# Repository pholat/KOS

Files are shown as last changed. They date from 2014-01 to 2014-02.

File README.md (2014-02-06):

KOS
===

Another RepRap controller based on teensylu/printrboard and more. Controller is designed in last developer version of KiCAD EDA, moreover it is compatibile with teensylu 0.8. If you use Marlin, all you need is to choose teensylu board.

Teensylu-lvlup-0.9v125 is licenced under Creative Commons Attribution-ShareAlike 4.0 International 
http://creativecommons.org/licenses/by-sa/4.0/legalcode

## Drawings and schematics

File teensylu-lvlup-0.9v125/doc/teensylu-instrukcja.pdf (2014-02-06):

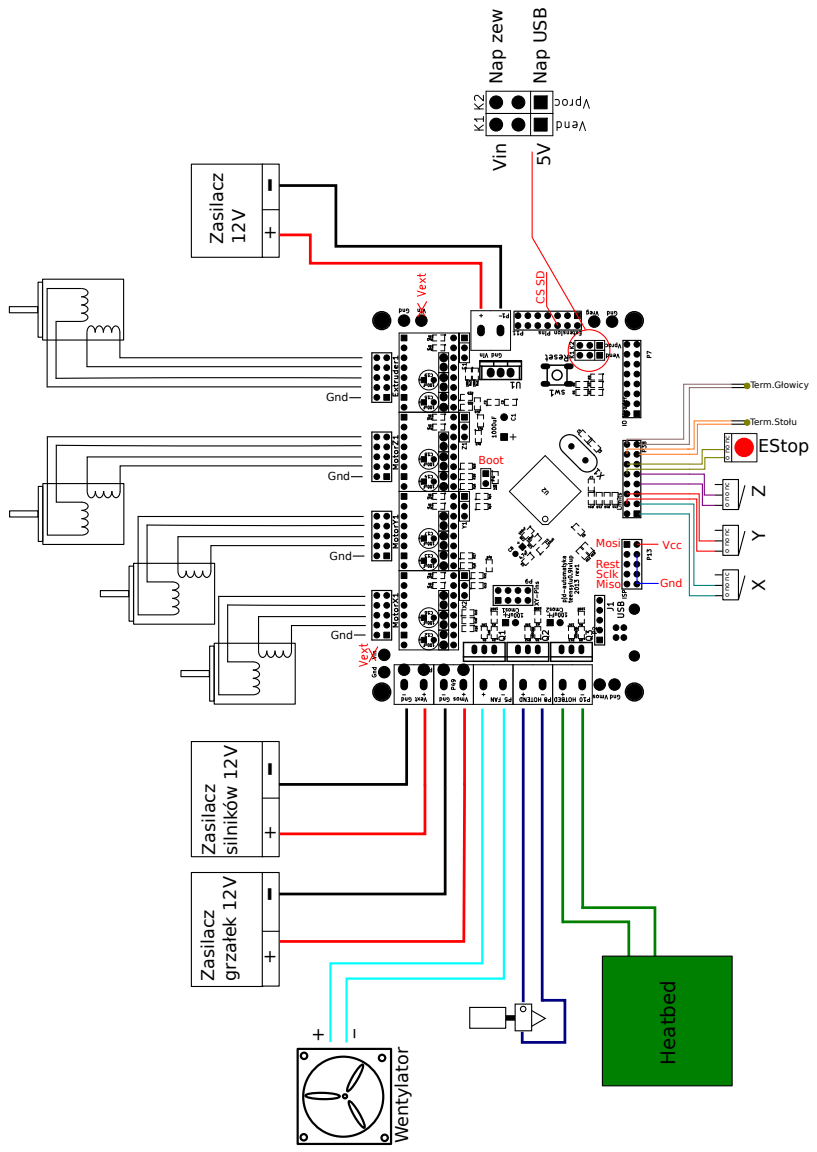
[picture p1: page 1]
Zasilacz; grzałek 12V; silników 12V + - + -; Heatbed; Term.Stołu; Term.Głowicy; Nap zew; Nap USB; Vin; Gnd; Mosi; Vcc; Rest Sclk Miso; Boot; EStop; Wentylator

## 1 Krańcówki

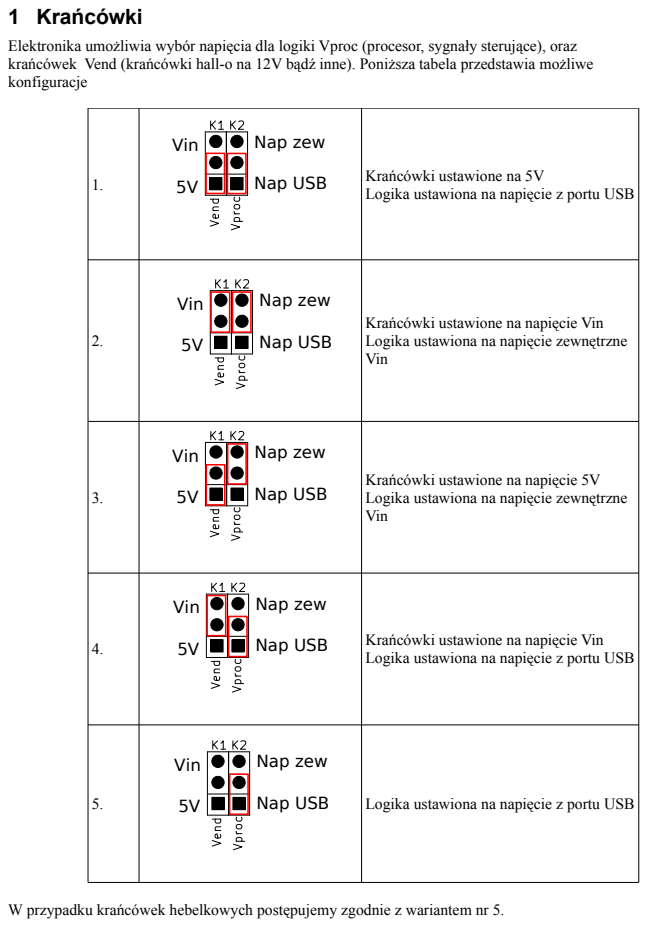
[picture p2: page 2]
Nap zew; Nap USB; Vin

Elektronika umożliwia wybór napięcia dla logiki Vproc (procesor, sygnały sterujące), oraz
krańcówek Vend (krańcówki hall-o na 12V bądź inne). Poniższa tabela przedstawia możliwe
konfiguracje

1. Krańcówki ustawione na 5V | Logika ustawiona na napięcie z portu USB

2. | Krańcówki ustawione na napięcie Vin Logika ustawiona na napięcie zewnętrzne Vin

3. | Krańcówki ustawione na napięcie 5V Logika ustawiona na napięcie zewnętrzne Vin

4. Krańcówki ustawione na napięcie Vin | Logika ustawiona na napięcie z portu USB

5. Logika ustawiona na napięcie z portu USB

W przypadku krańcówek hebelkowych postępujemy zgodnie z wariantem nr 5.

## 2 Stepstick

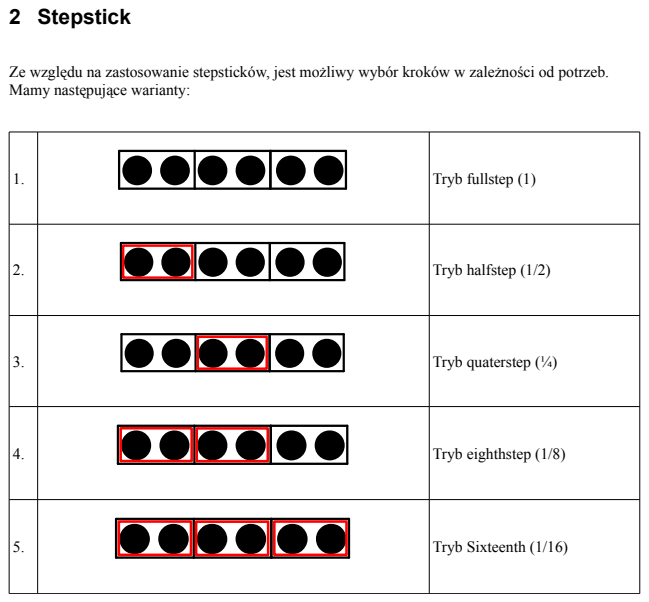
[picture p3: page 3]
1. Tryb fullstep (1); 2. Tryb halfstep (1/2); 3. Tryb quaterstep (¼); 4. Tryb eighthstep (1/8); 5. Tryb Sixteenth (1/16)

Ze względu na zastosowanie stepsticków, jest możliwy wybór kroków w zależności od potrzeb.
Mamy następujące warianty:

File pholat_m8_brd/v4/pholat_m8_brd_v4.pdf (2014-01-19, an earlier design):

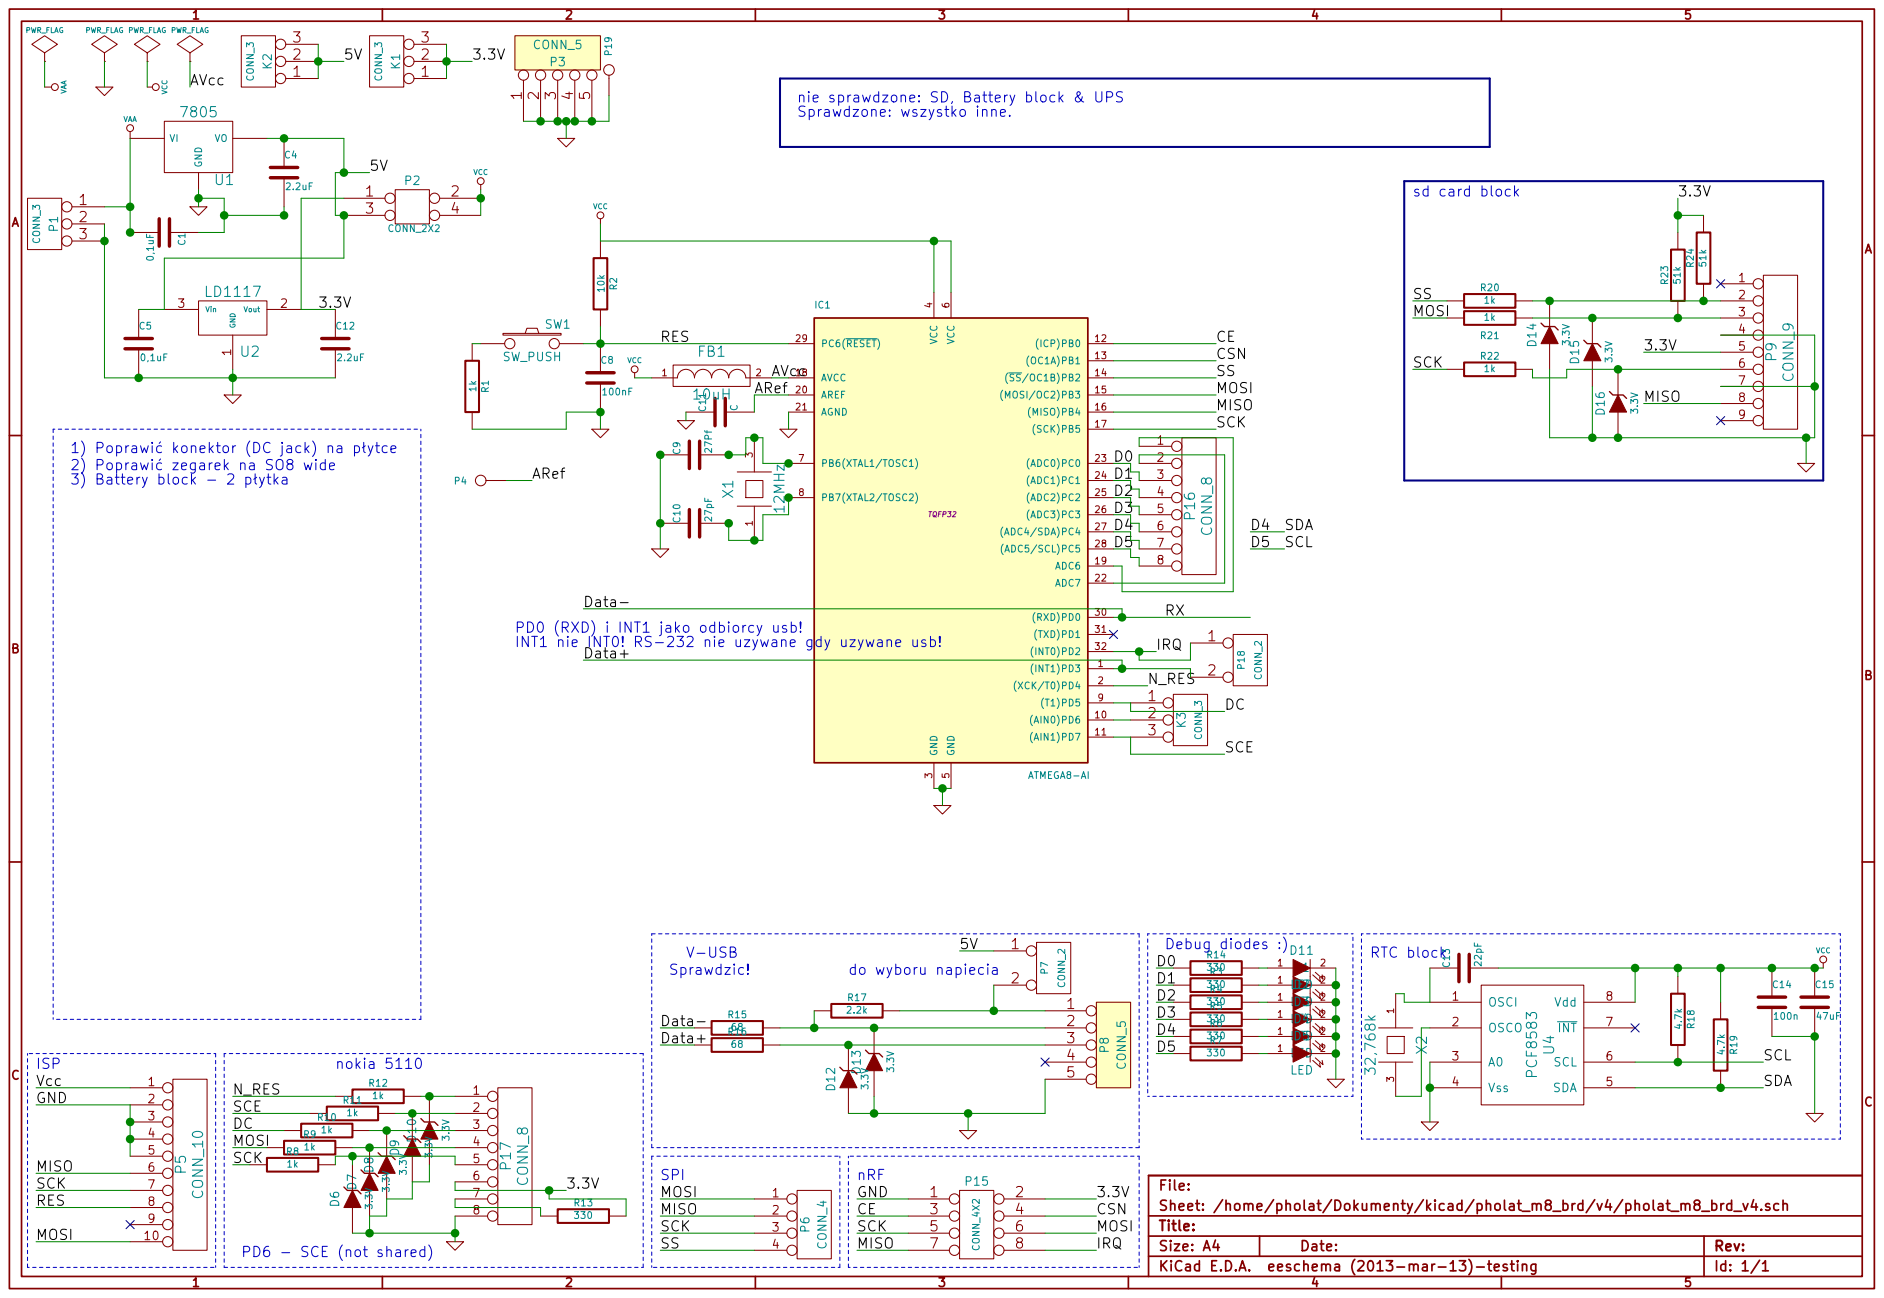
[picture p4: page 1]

nie sprawdzone: SD, Battery block & UPS
Sprawdzone: wszystko inne.

VCC 1) Poprawi konektor (DC jack) na pytce
2) Poprawi zegarek na SO8 wide
3) Battery block - 2 pytka

PD0 (RXD) i INT1 jako odbiorcy usb!
INT1 nie INT0! RS-232 nie uzywane gdy uzywane usb!

C Sheet: /home/pholat/Dokumenty/kicad/pholat_m8_brd/v4/pholat_m8_brd_v4.sch File: Title:

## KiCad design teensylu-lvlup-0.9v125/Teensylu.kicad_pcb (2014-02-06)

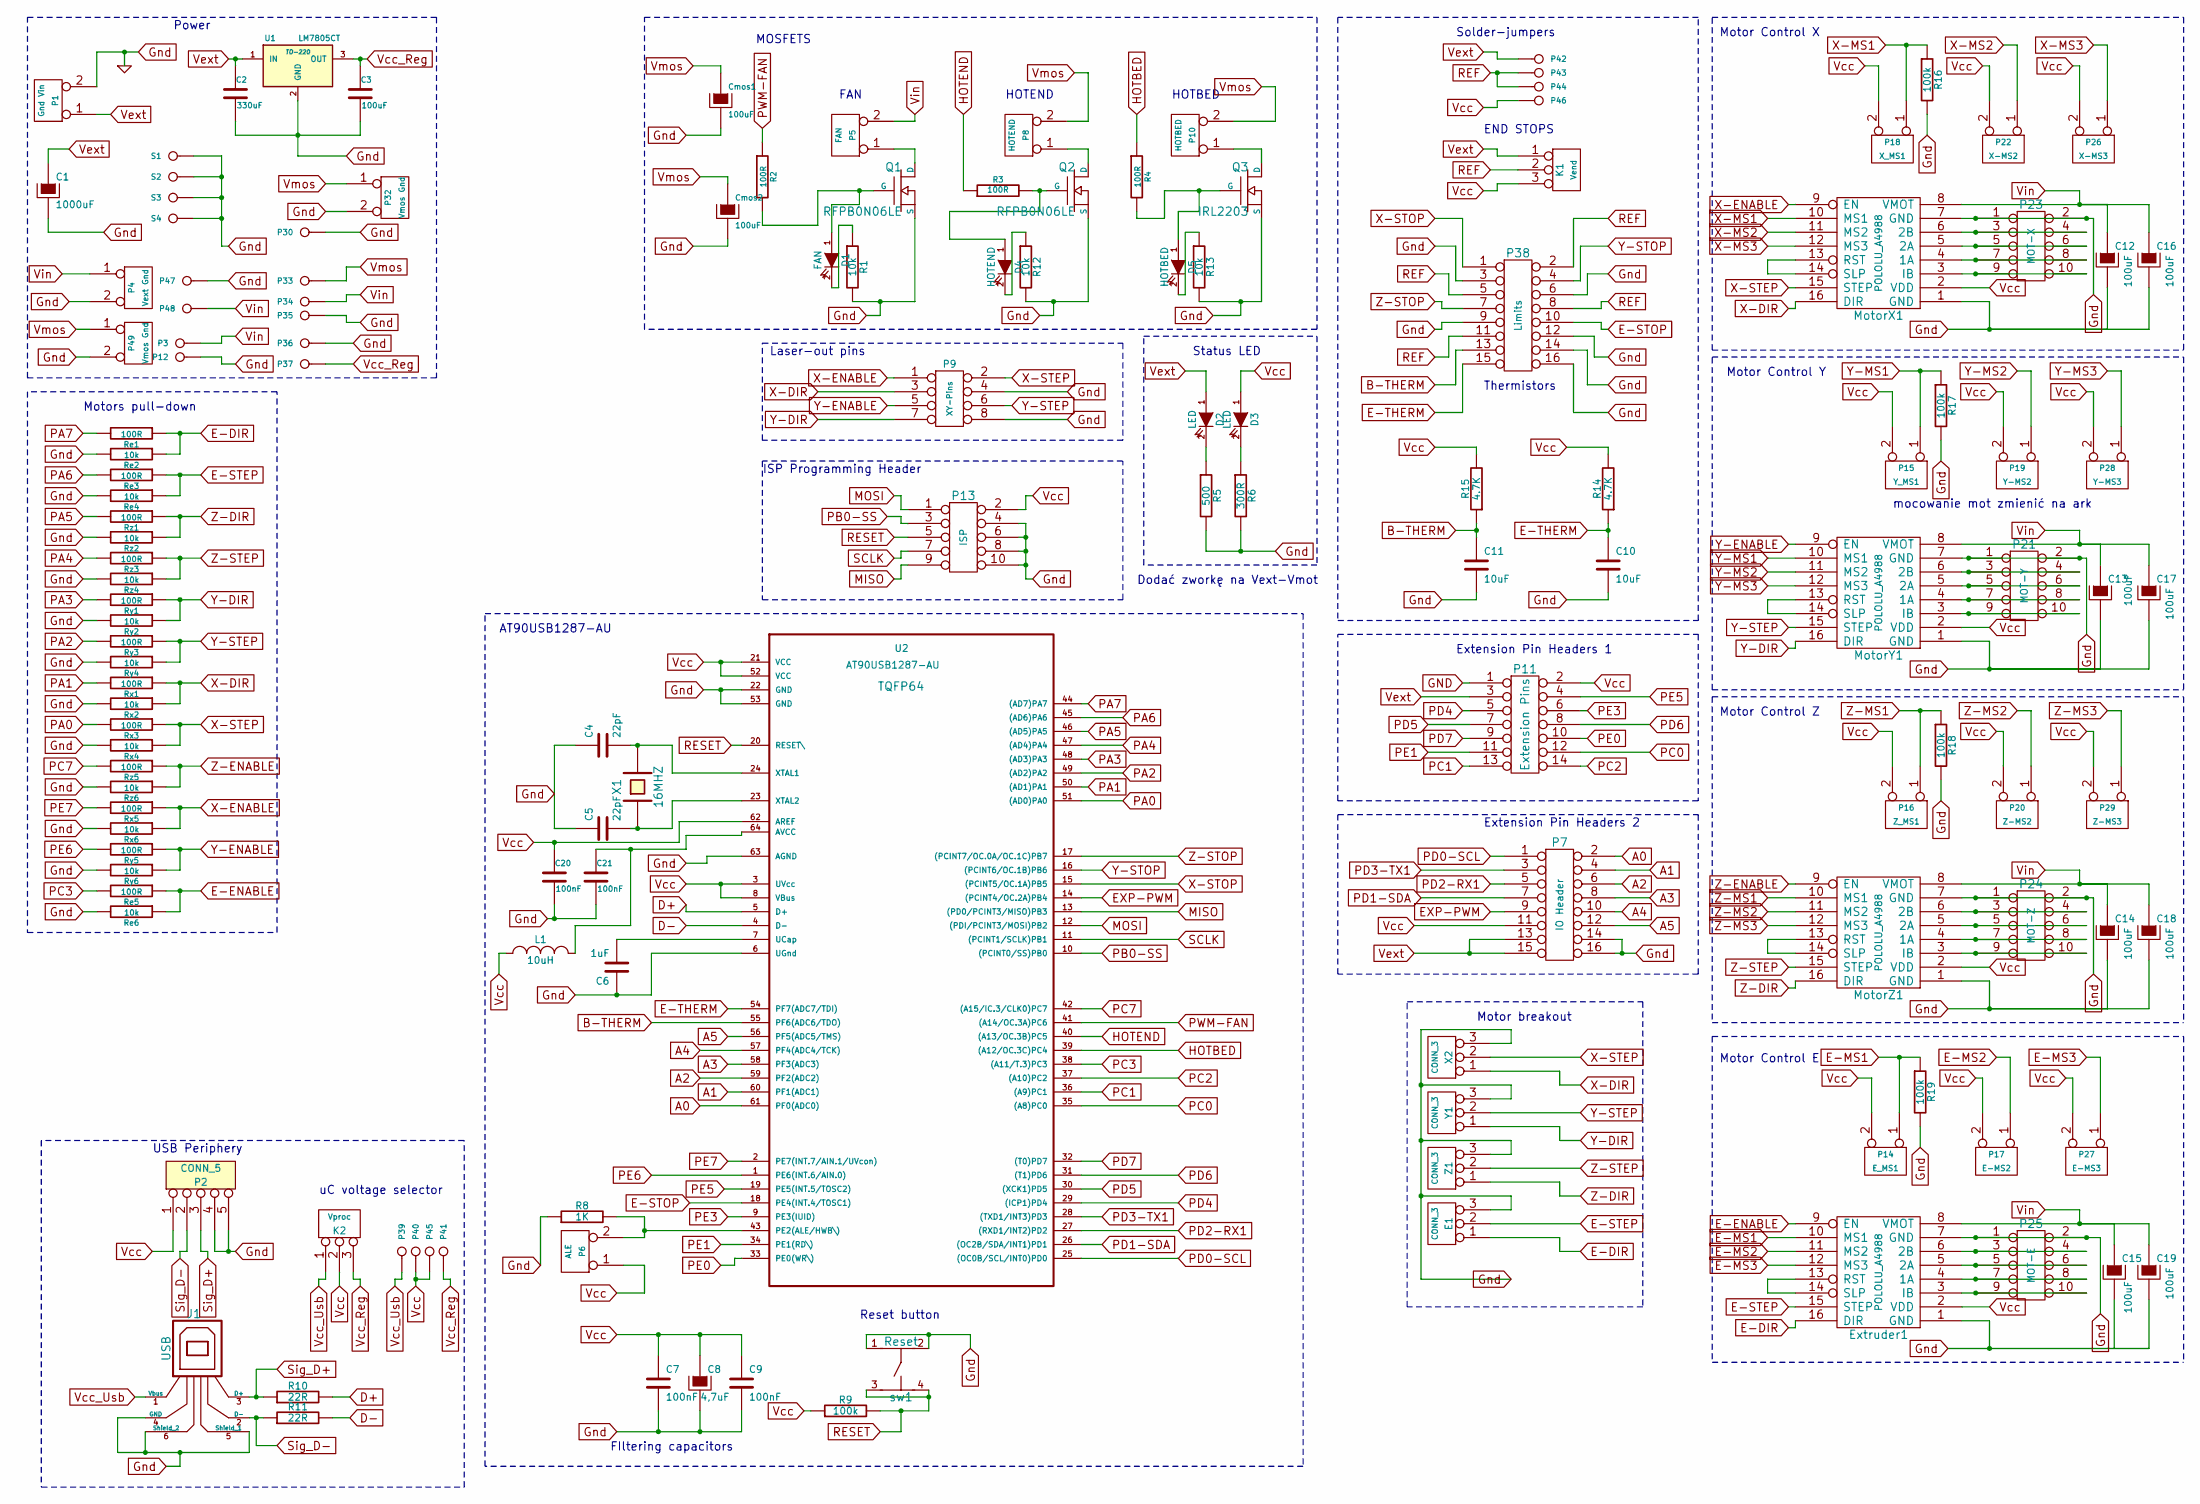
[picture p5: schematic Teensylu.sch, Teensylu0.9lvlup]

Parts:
C1: 1000uF
C2: 330uF
C3, C12, C13, C14, C15, C16, C17, C18, C19: 100uF
C4, C5: 22pF
C6: 1uF
C7, C9, C20, C21: 100nF
C8: 4,7uF
C10, C11: 10uF
Cmos1, Cmos2: 100uF
D1: FAN
D2, D3: LED
D4: HOTEND
D5: HOTBED
E1: CONN_3
Extruder1: POLOLU_A4988
J1: USB
K1: Vend
K2: Vproc
L1: 10uH
MotorX1: POLOLU_A4988
MotorY1: POLOLU_A4988
MotorZ1: POLOLU_A4988
P1: Gnd Vin
P2: CONN_5
P3, P34, P47: Vin
P4: Vext Gnd
P5: FAN
P6: ALE
P7: IO Header
P8: HOTEND
P9: XY-Pins
P10: HOTBED
P11: Extension Pins
P12, P30, P35, P36, P48: Gnd
P13: ISP
P14: E_MS1
P15: Y_MS1
P16: Z_MS1
P17: E-MS2
P18: X_MS1
P19: Y-MS2
P20: Z-MS2
P21: MOT-Y
P22: X-MS2
P23: MOT-X
P24: MOT-Z
P25: MOT-E
P26: X-MS3
P27: E-MS3
P28: Y-MS3
P29: Z-MS3
P32, P49: Vmos Gnd
P33: Vmos
P37: Vreg
P38: Limits
P39, P40, P41, P42, P43, P44, P45, P46: CONN_1
Q1, Q2: RFPB0N06LE
Q3: IRL2203
R1, R12, R13: 10k
R2, R3, R4: 100R
R5: 500
R6: 300R
R8: 1K
R9, R16, R17, R18, R19: 100k
R10, R11: 22R
R14, R15: 4.7K
Re1, Re3, Re5: 100R
Re2, Re4, Re6: 10k
Rx1, Rx3, Rx5: 100R
Rx2, Rx4, Rx6: 10k
Ry1, Ry3, Ry5: 100R
Ry2, Ry4, Ry6: 10k
Rz1, Rz3, Rz5: 100R
Rz2, Rz4, Rz6: 10k
S1, S2, S3, S4: S
U1: LM7805CT; TO-220
U2: AT90USB1287-AU
X1: 16MHZ
X2: CONN_3
Y1: CONN_3
Z1: CONN_3
sw1: Reset

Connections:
A0: P7.2, U2.61 (PF0(ADC0))
A1: P7.4, U2.60 (PF1(ADC1))
A2: P7.6, U2.59 (PF2(ADC2))
A3: P7.8, U2.58 (PF3(ADC3))
A4: P7.10, U2.57 (PF4(ADC4/TCK))
A5: P7.12, U2.56 (PF5(ADC5/TMS))
B-THERM: C11.1, P38.13, R15.1, U2.55 (PF6(ADC6/TDO))
D+: R10.2, U2.5 (D+)
D-: R11.2, U2.4 (D-)
E-DIR: E1.1, Extruder1.16 (DIR), Re1.1, Re2.1
E-ENABLE: Extruder1.9 (EN), Re5.1, Re6.1
E-MS1: Extruder1.10 (MS1), P14.1, R19.1
E-MS2: Extruder1.11 (MS2), P17.1
E-MS3: Extruder1.12 (MS3), P27.1
E-STEP: E1.2 (PM), Extruder1.15 (STEP), Re3.1, Re4.1
E-STOP: P38.10, U2.18 (PE4(INT.4/TOSC1))
E-THERM: C10.1, P38.15, R14.1, U2.54 (PF7(ADC7/TDI))
EXP-PWM: P7.9, U2.14 ((PCINT4/OC.2A)PB4)
GND: C1.2, C2.2, C3.2, C4.1, C5.1, C6.1, C7.2, C8.2, C9.2, C10.2, C11.2, C12.2, C13.2, C14.2, C15.2, C16.2, C17.2, C18.2, C19.2, C20.2, C21.2, Cmos1.2, Cmos2.2, E1.3, Extruder1.1 (GND), Extruder1.7 (GND), J1.4 (GND), J1.5 (Shield_1), J1.6 (Shield_2), MotorX1.1 (GND), MotorX1.7 (GND), MotorY1.1 (GND), MotorY1.7 (GND), MotorZ1.1 (GND), MotorZ1.7 (GND), P1.2 (PM), P2.4, P2.5, P4.2 (PM), P7.14, P7.16, P9.4, P9.8, P11.1, P12.1, P13.4, P13.6, P13.8, P13.10, P21.1, P21.2, P23.1, P23.2, P24.1, P24.2, P25.1, P25.2, P30.1, P32.2 (PM), P35.1, P36.1, P38.3, P38.6, P38.9, P38.12, P38.14, P38.16, P47.1, P49.2 (PM), Q1.S, Q2.S, Q3.S, R1.2, R5.2, R6.2, R8.1, R12.2, R13.2, R16.2, R17.2, R18.2, R19.2, Re2.2, Re4.2, Re6.2, Rx2.2, Rx4.2, Rx6.2, Ry2.2, Ry4.2, Ry6.2, Rz2.2, Rz4.2, Rz6.2, S1.1, S2.1, S3.1, S4.1, U1.2 (GND), U2.6 (UGnd), U2.22 (GND), U2.53 (GND), U2.63 (AGND), X2.3, Y1.3, Z1.3, sw1.1, sw1.2
HOTBED: R4.1, U2.39 ((A12/OC.3C)PC4)
HOTEND: R3.1, U2.40 ((A13/OC.3B)PC5)
MISO: P13.9, U2.13 ((PD0/PCINT3/MISO)PB3)
MOSI: P13.1, U2.12 ((PDI/PCINT3/MOSI)PB2)
unnamed: C6.2, U2.7 (UCap)
unnamed: C21.1, L1.2, U2.64 (AVCC)
unnamed: D3.2 (K), R6.1
unnamed: MotorX1.13 (RST), MotorX1.14 (SLP)
unnamed: P5.1, Q1.D
unnamed: P10.1, Q3.D
unnamed: P8.1, Q2.D
unnamed: MotorY1.13 (RST), MotorY1.14 (SLP)
unnamed: P6.2 (PM), R8.2, U2.43 (PE2(ALE/HWB\))
unnamed: D2.2 (K), R5.1
unnamed: D4.1 (A), Q2.G, R3.2
unnamed: D1.1 (A), Q1.G, R2.2
unnamed: MotorZ1.13 (RST), MotorZ1.14 (SLP)
unnamed: Extruder1.13 (RST), Extruder1.14 (SLP)
unnamed: D5.2 (K), R13.1
unnamed: D5.1 (A), Q3.G, R4.2
unnamed: D4.2 (K), R12.1
unnamed: D1.2 (K), R1.1
unnamed: C4.2, U2.24 (XTAL1), X1.2
unnamed: C5.2, U2.23 (XTAL2), X1.1
unnamed: MotorZ1.3 (IB), P24.9, P24.10
unnamed: MotorZ1.4 (1A), P24.7, P24.8
unnamed: MotorZ1.5 (2A), P24.5, P24.6
unnamed: MotorZ1.6 (2B), P24.3, P24.4
unnamed: Extruder1.3 (IB), P25.9, P25.10
unnamed: Extruder1.4 (1A), P25.7, P25.8
unnamed: Extruder1.5 (2A), P25.5, P25.6
unnamed: Extruder1.6 (2B), P25.3, P25.4
unnamed: MotorX1.3 (IB), P23.9, P23.10
unnamed: MotorX1.4 (1A), P23.7, P23.8
unnamed: MotorX1.5 (2A), P23.5, P23.6
unnamed: MotorX1.6 (2B), P23.3, P23.4
unnamed: MotorY1.3 (IB), P21.9, P21.10
unnamed: MotorY1.4 (1A), P21.7, P21.8
unnamed: MotorY1.5 (2A), P21.5, P21.6
unnamed: MotorY1.6 (2B), P21.3, P21.4
PA0: Rx3.2, U2.51 ((AD0)PA0)
PA1: Rx1.2, U2.50 ((AD1)PA1)
PA2: Ry3.2, U2.49 ((AD2)PA2)
PA3: Ry1.2, U2.48 ((AD3)PA3)
PA4: Rz3.2, U2.47 ((AD4)PA4)
PA5: Rz1.2, U2.46 ((AD5)PA5)
PA6: Re3.2, U2.45 ((AD6)PA6)
PA7: Re1.2, U2.44 ((AD7)PA7)
PB0-SS: P13.3, U2.10 ((PCINT0/SS)PB0)
PC0: P11.12, U2.35 ((A8)PC0)
PC1: P11.13, U2.36 ((A9)PC1)
PC2: P11.14, U2.37 ((A10)PC2)
PC3: Re5.2, U2.38 ((A11/T.3)PC3)
PC7: Rz5.2, U2.42 ((A15/IC.3/CLK0)PC7)
PD0-SCL: P7.1, U2.25 ((OC0B/SCL/INT0)PD0)
PD1-SDA: P7.7, U2.26 ((OC2B/SDA/INT1)PD1)
PD2-RX1: P7.5, U2.27 ((RXD1/INT2)PD2)
PD3-TX1: P7.3, U2.28 ((TXD1/INT3)PD3)
PD4: P11.5, U2.29 ((ICP1)PD4)
PD5: P11.7, U2.30 ((XCK1)PD5)
PD6: P11.8, U2.31 ((T1)PD6)
PD7: P11.9, U2.32 ((T0)PD7)
PE0: P11.10, U2.33 (PE0(WR\))
PE1: P11.11, U2.34 (PE1(RD\))
PE3: P11.6, U2.9 (PE3(IUID))
PE5: P11.4, U2.19 (PE5(INT.5/TOSC2))
PE6: Ry5.2, U2.1 (PE6(INT.6/AIN.0))
PE7: Rx5.2, U2.2 (PE7(INT.7/AIN.1/UVcon))
PWM-FAN: R2.1, U2.41 ((A14/OC.3A)PC6)
REF: K1.2 (PM), P38.2, P38.5, P38.8, P38.11, P43.1, P44.1
RESET: P13.5, R9.2, U2.20 (RESET\), sw1.3, sw1.4
SCLK: P13.7, U2.11 ((PCINT1/SCLK)PB1)
Sig_D+: J1.3 (D+), P2.3, R10.1
Sig_D-: J1.2 (D-), P2.2, R11.1
Vcc: C7.1, C8.1, C9.1, C20.1, D3.1 (A), Extruder1.2 (VDD), K1.3, K2.2 (PM), L1.1, MotorX1.2 (VDD), MotorY1.2 (VDD), MotorZ1.2 (VDD), P2.1, P6.1, P7.11, P11.2, P13.2, P14.2 (PM), P15.2 (PM), P16.2 (PM), P17.2 (PM), P18.2 (PM), P19.2 (PM), P20.2 (PM), P22.2 (PM), P26.2 (PM), P27.2 (PM), P28.2 (PM), P29.2 (PM), P40.1, P45.1, P46.1, R9.1, R14.2, R15.2, U2.3 (UVcc), U2.8 (VBus), U2.21 (VCC), U2.52 (VCC), U2.62 (AREF)
Vcc_Reg: C3.1, K2.3, P37.1, P41.1, U1.3 (OUT)
Vcc_Usb: J1.1 (Vbus), K2.1, P39.1
Vext: C1.1, C2.1, D2.1 (A), K1.1, P1.1, P7.13, P7.15, P11.3, P42.1, U1.1 (IN)
Vin: C12.1, C13.1, C14.1, C15.1, C16.1, C17.1, C18.1, C19.1, Extruder1.8 (VMOT), MotorX1.8 (VMOT), MotorY1.8 (VMOT), MotorZ1.8 (VMOT), P3.1, P4.1, P5.2 (PM), P34.1, P48.1
Vmos: Cmos1.1, Cmos2.1, P8.2 (PM), P10.2 (PM), P32.1, P33.1, P49.1
X-DIR: MotorX1.16 (DIR), P9.3, Rx1.1, Rx2.1, X2.1
X-ENABLE: MotorX1.9 (EN), P9.1, Rx5.1, Rx6.1
X-MS1: MotorX1.10 (MS1), P18.1, R16.1
X-MS2: MotorX1.11 (MS2), P22.1
X-MS3: MotorX1.12 (MS3), P26.1
X-STEP: MotorX1.15 (STEP), P9.2, Rx3.1, Rx4.1, X2.2 (PM)
X-STOP: P38.1, U2.15 ((PCINT5/OC.1A)PB5)
Y-DIR: MotorY1.16 (DIR), P9.7, Ry1.1, Ry2.1, Y1.1
Y-ENABLE: MotorY1.9 (EN), P9.5, Ry5.1, Ry6.1
Y-MS1: MotorY1.10 (MS1), P15.1, R17.1
Y-MS2: MotorY1.11 (MS2), P19.1
Y-MS3: MotorY1.12 (MS3), P28.1
Y-STEP: MotorY1.15 (STEP), P9.6, Ry3.1, Ry4.1, Y1.2 (PM)
Y-STOP: P38.4, U2.16 ((PCINT6/OC.1B)PB6)
Z-DIR: MotorZ1.16 (DIR), Rz1.1, Rz2.1, Z1.1
Z-ENABLE: MotorZ1.9 (EN), Rz5.1, Rz6.1
Z-MS1: MotorZ1.10 (MS1), P16.1, R18.1
Z-MS2: MotorZ1.11 (MS2), P20.1
Z-MS3: MotorZ1.12 (MS3), P29.1
Z-STEP: MotorZ1.15 (STEP), Rz3.1, Rz4.1, Z1.2 (PM)
Z-STOP: P38.7, U2.17 ((PCINT7/OC.0A/OC.1C)PB7)

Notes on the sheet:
Status LED
ISP Programming Header
Extension Pin Headers 2
MOSFETS
END STOPS
FIltering capacitors
Reset button
Motor Control Y
Motor Control Z
Motor Control E
Motor Control X
Thermistors
Extension Pin Headers 1
AT90USB1287-AU
FAN
HOTEND
HOTBED
Laser-out pins
Solder-jumpers
USB Periphery
uC voltage selector
Motors pull-down
Power
Motor breakout
mocowanie mot zmienić na ark
Dodać zworkę na Vext-Vmot

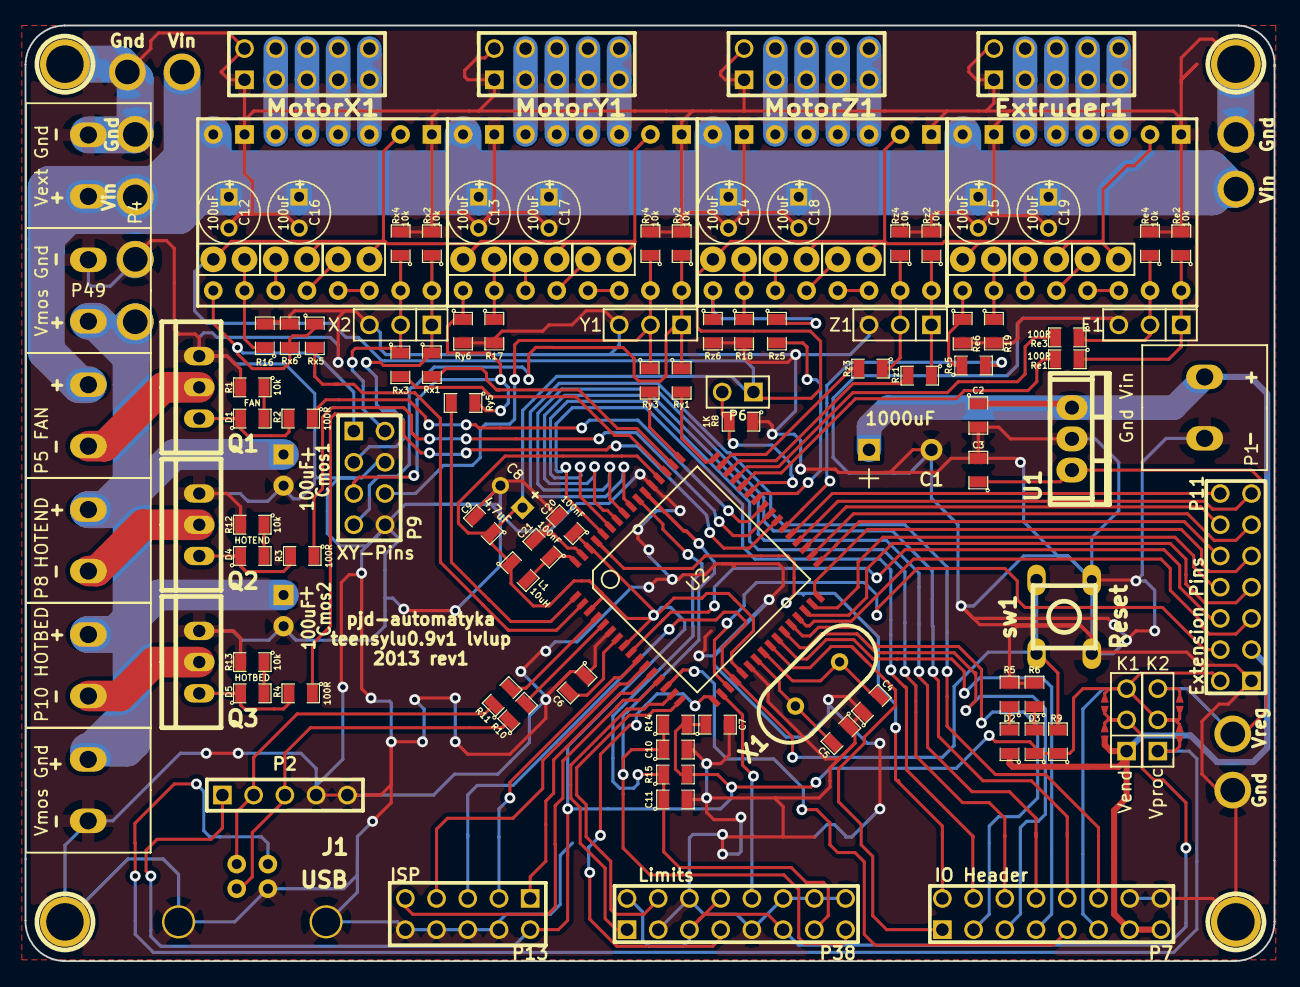
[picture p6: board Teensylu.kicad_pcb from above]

Board: 2 copper layers, 101.6 x 76.1 mm, 141 parts (0 on the bottom side), 120 nets.

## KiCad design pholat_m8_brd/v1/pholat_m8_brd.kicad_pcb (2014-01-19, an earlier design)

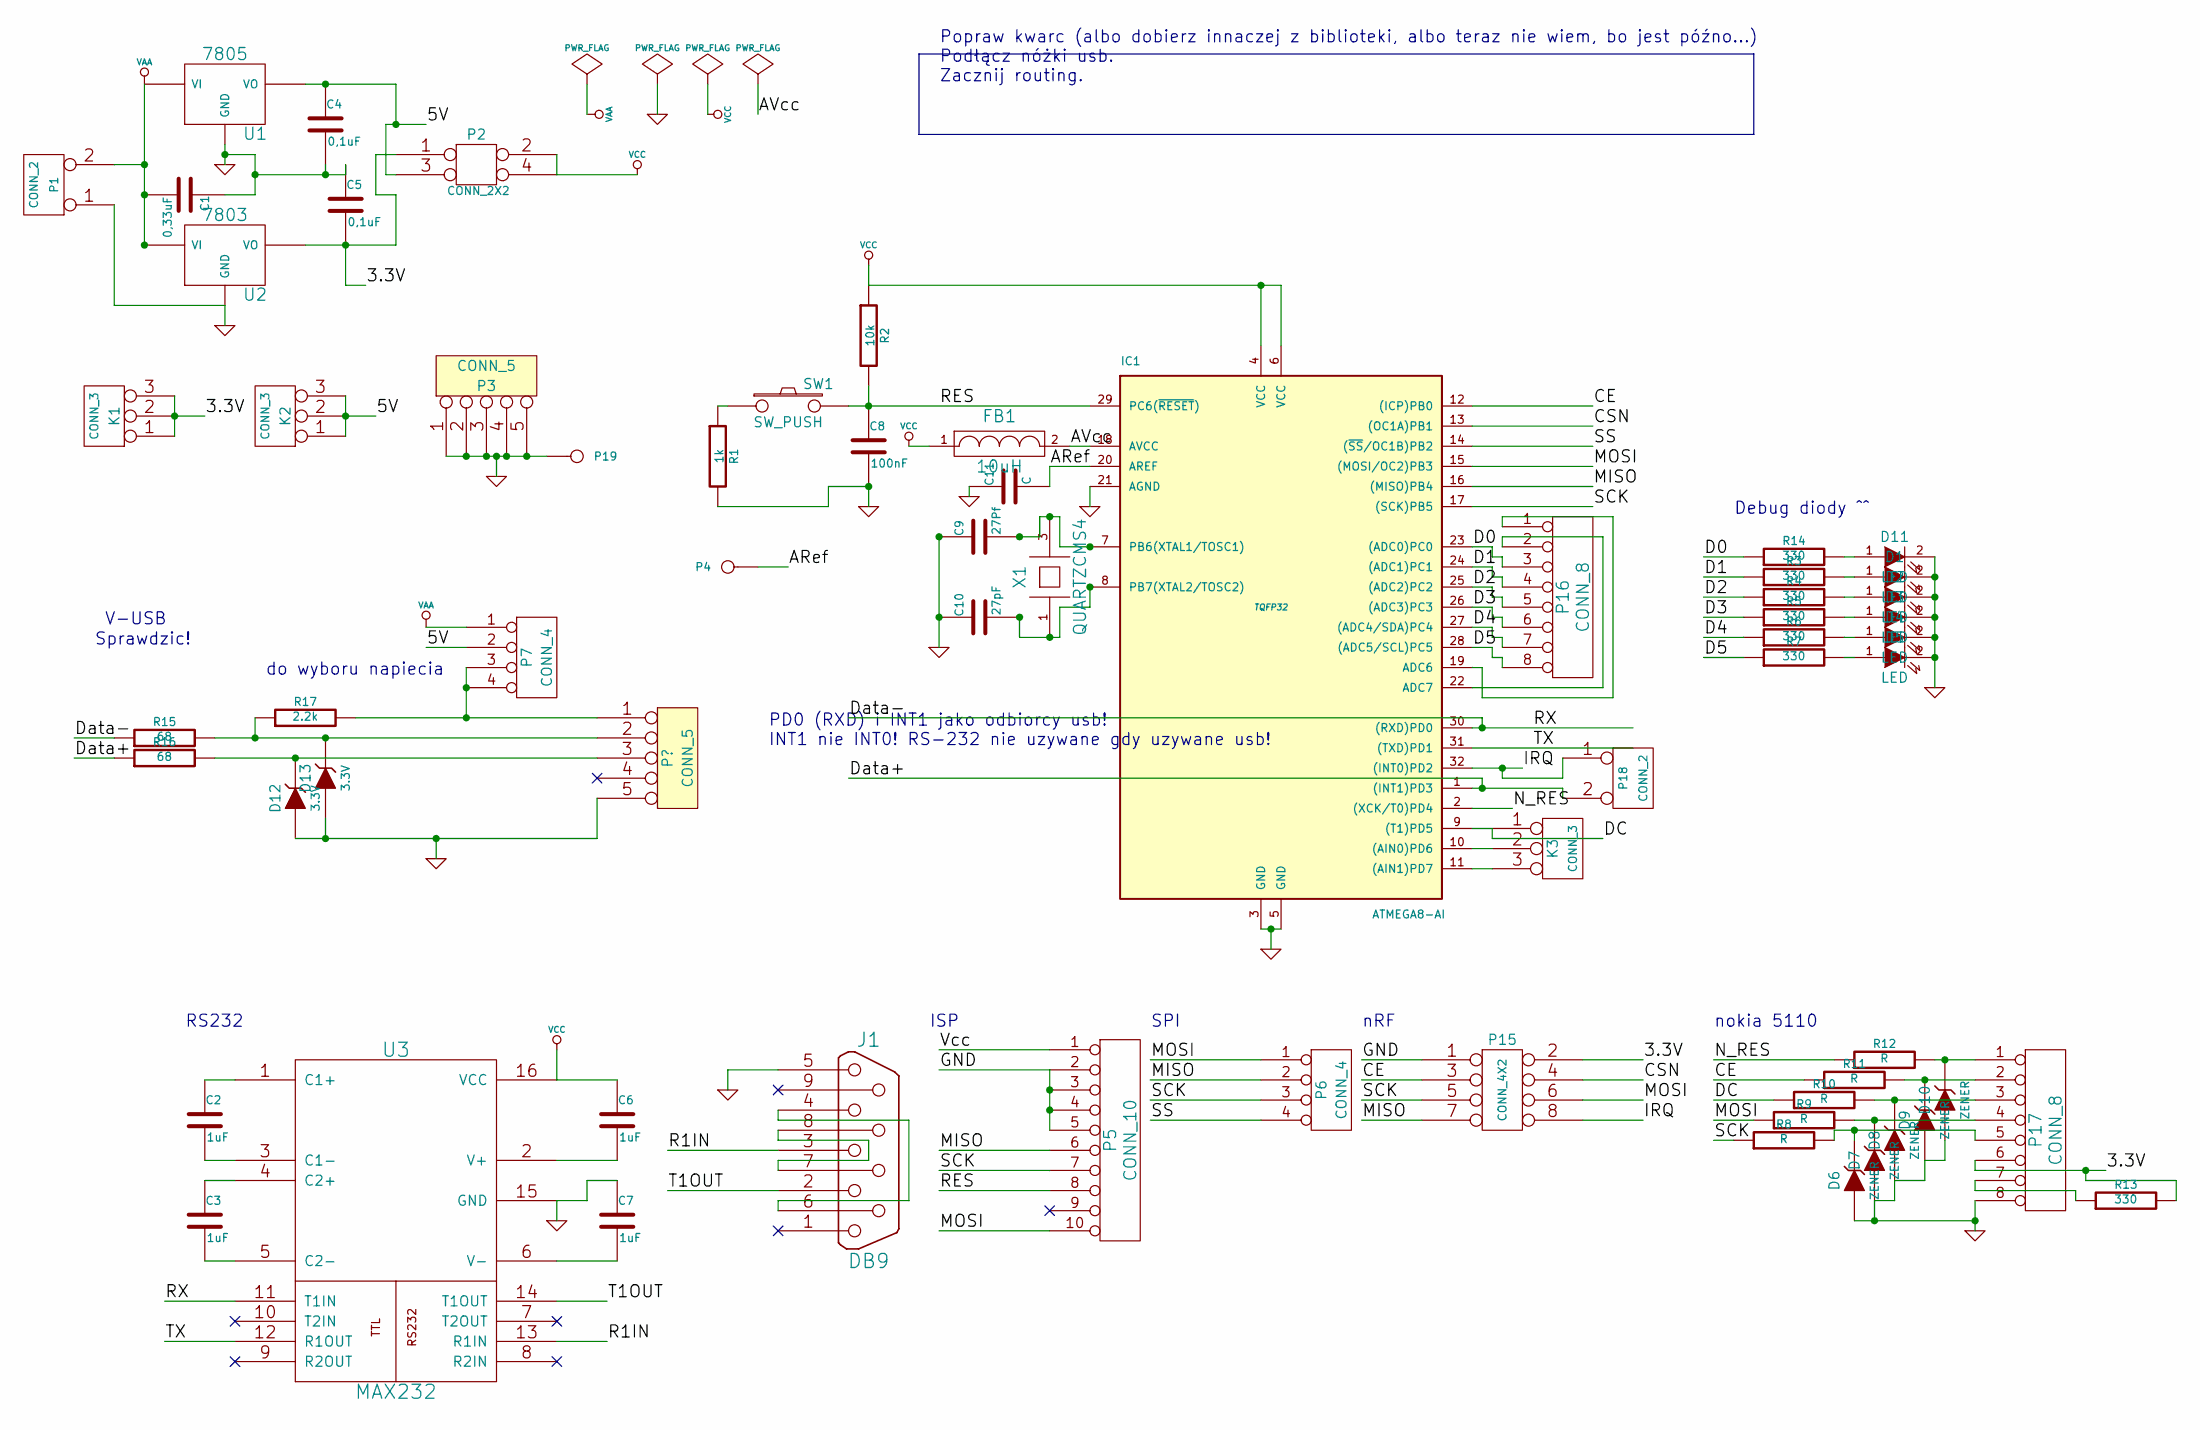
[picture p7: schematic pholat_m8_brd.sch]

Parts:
C1: 0,33uF
C2, C3, C6, C7: 1uF
C4, C5: 0,1uF
C8: 100nF
C9: 27Pf
C10: 27pF
C11: C
D1, D2, D3, D4, D5, D11: LED
D6, D7, D8, D9, D10: ZENER
D12, D13: 3.3V
FB1: 10uH
IC1: ATMEGA8-AI; TQFP32
J1: DB9
K1, K2, K3: CONN_3
P1, P18: CONN_2
P2: CONN_2X2
P3: CONN_5
P4, P19: CONN_1
P5: CONN_10
P6, P7: CONN_4
P15: CONN_4X2
P16, P17: CONN_8
R1: 1k
R2: 10k
R3, R4, R5, R6, R7, R13, R14: 330
R8, R9, R10, R11, R12: R
R15, R16: 68
R17: 2.2k
SW1: SW_PUSH
U1: 7805
U2: 7803
U3: MAX232
X1: QUARTZCMS4

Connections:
/3.3V: C5.2, K1.1, K1.2 (PM), K1.3, P2.1, P15.2, P17.6, R13.2, U2.3 (VO)
/5V: C4.1, K2.1, K2.2 (PM), K2.3, P2.3, P7.2, U1.3 (VO)
/ARef: C11.2, IC1.20 (AREF), P4.1
/AVcc: FB1.2, IC1.18 (AVCC)
/CE: IC1.12 ((ICP)PB0), P15.3, R11.1
/CSN: IC1.13 ((OC1A)PB1), P15.4
/D0: IC1.23 ((ADC0)PC0), P16.3, R14.1
/D1: IC1.24 ((ADC1)PC1), P16.4, R3.1
/D2: IC1.25 ((ADC2)PC2), P16.5, R4.1
/D3: IC1.26 ((ADC3)PC3), P16.6, R5.1
/D4: IC1.27 ((ADC4/SDA)PC4), P16.7, R6.1
/D5: IC1.28 ((ADC5/SCL)PC5), P16.8, R7.1
/DC: IC1.9 ((T1)PD5), K3.1, R10.1
/Data+: IC1.1 ((INT1)PD3), P18.2 (PM), R16.1
/Data-: IC1.30 ((RXD)PD0), R15.1, U3.11 (T1IN)
/IRQ: IC1.32 ((INT0)PD2), P15.8, P18.1
/MISO: IC1.16 ((MISO)PB4), P5.6, P6.2, P15.7
/MOSI: IC1.15 ((MOSI/OC2)PB3), P5.10, P6.1, P15.6, R9.1
/N_RES: IC1.2 ((XCK/T0)PD4), R12.1
/R1IN: J1.3, U3.13 (R1IN)
/RES: C8.1, IC1.29 (PC6(~RESET~)), P5.8, R2.2, SW1.2
/SCK: IC1.17 ((SCK)PB5), P5.7, P6.3, P15.5, R8.1
/SS: IC1.14 ((~SS~/OC1B)PB2), P6.4
/T1OUT: J1.2, U3.14 (T1OUT)
/TX: IC1.31 ((TXD)PD1), U3.12 (R1OUT)
GND: C1.1, C4.2, C5.1, C7.1, C8.2, C9.1, C10.1, C11.1, D1.2 (K), D2.2 (K), D3.2 (K), D4.2 (K), D5.2 (K), D6.1 (A), D7.1 (A), D8.1 (A), D9.1 (A), D10.1 (A), D11.2 (K), D12.1 (A), D13.1 (A), IC1.3 (GND), IC1.5 (GND), IC1.21 (AGND), J1.5, P1.1, P3.1, P3.2, P3.3, P3.4, P3.5, P5.2, P5.3, P5.4, P5.5, P15.1, P17.8, P19.1, R1.2, U1.2 (GND), U2.2 (GND), U3.15 (GND); also elsewhere on the board
unnamed: C7.2, U3.6 (V-)
unnamed: C3.2, U3.5 (C2-)
unnamed: C3.1, U3.4 (C2+)
unnamed: C2.2, U3.3 (C1-)
unnamed: C2.1, U3.1 (C1+)
unnamed: D5.1 (A), R7.2
unnamed: D4.1 (A), R6.2
unnamed: D3.1 (A), R5.2
unnamed: D2.1 (A), R4.2
unnamed: D1.1 (A), R3.2
unnamed: J1.7, J1.8
unnamed: J1.4, J1.6
unnamed: C6.2, U3.2 (V+)
unnamed: IC1.19 (ADC6), P16.1
unnamed: IC1.22 (ADC7), P16.2
unnamed: IC1.11 ((AIN1)PD7), K3.3
unnamed: IC1.10 ((AIN0)PD6), K3.2 (PM)
unnamed 43: D13.2 (K), R15.2, R17.1; also elsewhere on the board
unnamed 45: D12.2 (K), R16.2; also elsewhere on the board
unnamed: D11.1 (A), R14.2
unnamed: P17.7, R13.1
unnamed: R1.1, SW1.1
unnamed: D6.2 (K), P17.5, R8.2
unnamed 51: P7.3, P7.4, R17.2; also elsewhere on the board
unnamed: C10.2, IC1.8 (PB7(XTAL2/TOSC2)), X1.1
unnamed: C9.2, IC1.7 (PB6(XTAL1/TOSC1)), X1.3
unnamed: D7.2 (K), P17.4, R9.2
unnamed: D9.2 (K), P17.2, R11.2
unnamed: D8.2 (K), P17.3, R10.2
unnamed: D10.2 (K), P17.1, R12.2
VAA: C1.2, P1.2 (PM), P7.1, U1.1 (VI), U2.1 (VI)
VCC: C6.1, FB1.1, IC1.4 (VCC), IC1.6 (VCC), P2.2, P2.4, P5.1, R2.1, U3.16 (VCC)

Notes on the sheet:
ISP
SPI
nRF
RS232
nokia 5110
V-USB
Sprawdzic!
PD0 (RXD) i INT1 jako odbiorcy usb! INT1 nie INT0! RS-232 nie uzywane gdy uzywane usb!
Debug diody ^^
Popraw kwarc (albo dobierz innaczej z biblioteki, albo teraz nie wiem, bo jest późno...) Podłącz nóżki usb. Zacznij routing.
do wyboru napiecia

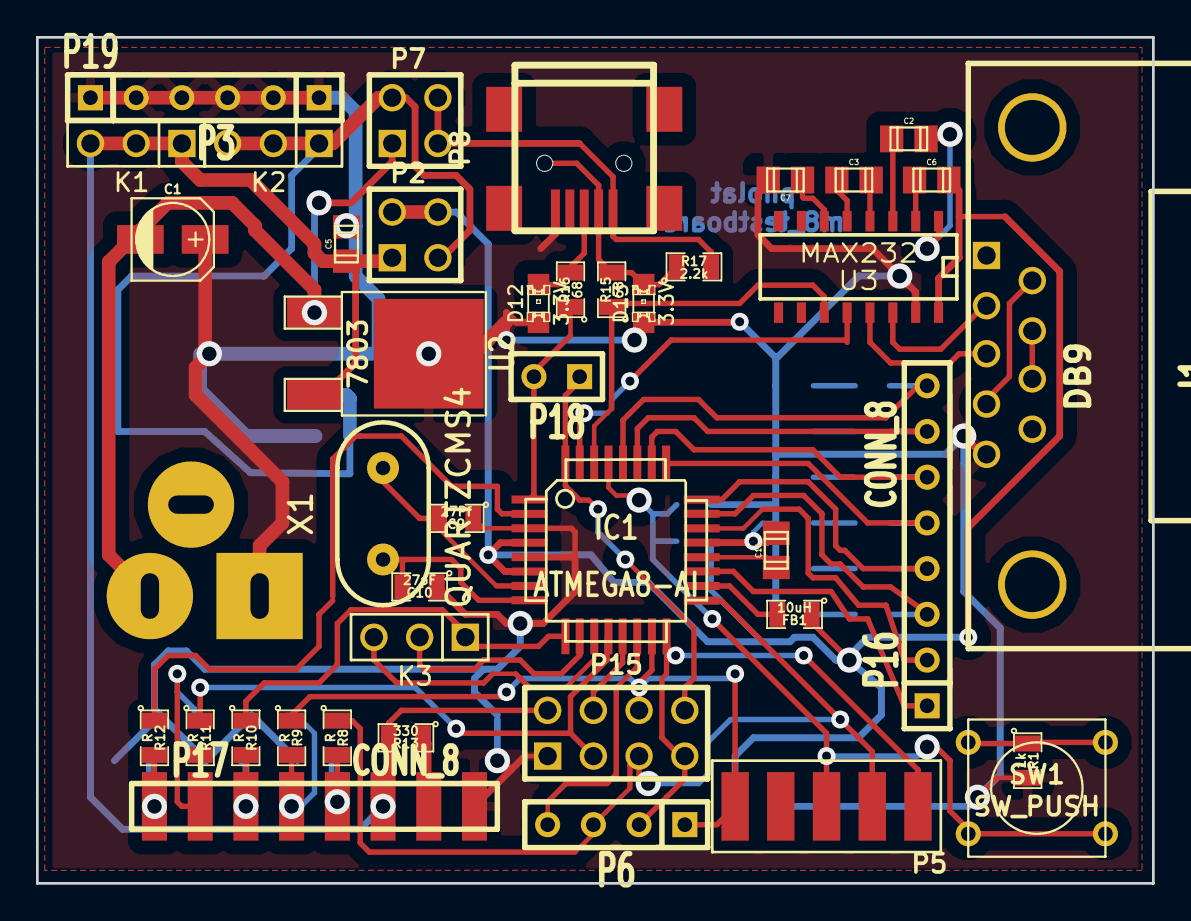
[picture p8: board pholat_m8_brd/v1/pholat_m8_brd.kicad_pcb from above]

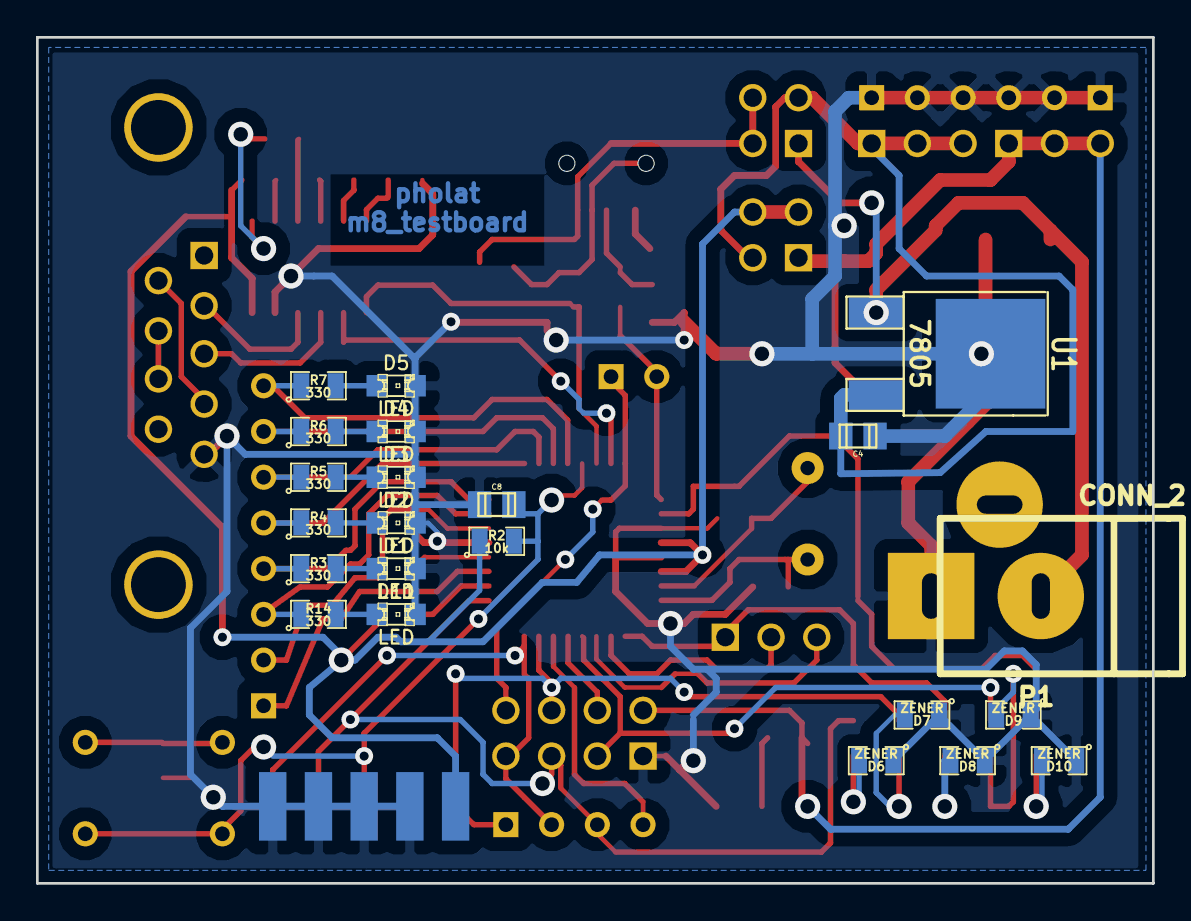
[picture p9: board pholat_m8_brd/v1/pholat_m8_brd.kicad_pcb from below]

Board: 2 copper layers, 62.0 x 47.0 mm, 64 parts (22 on the bottom side), 58 nets.

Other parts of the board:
P8: CONN_5; USB_MINI_B

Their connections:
GND: P8.5; also elsewhere on the board
unnamed 43: P8.2; also elsewhere on the board
unnamed 45: P8.3; also elsewhere on the board
unnamed 51: P8.1; also elsewhere on the board

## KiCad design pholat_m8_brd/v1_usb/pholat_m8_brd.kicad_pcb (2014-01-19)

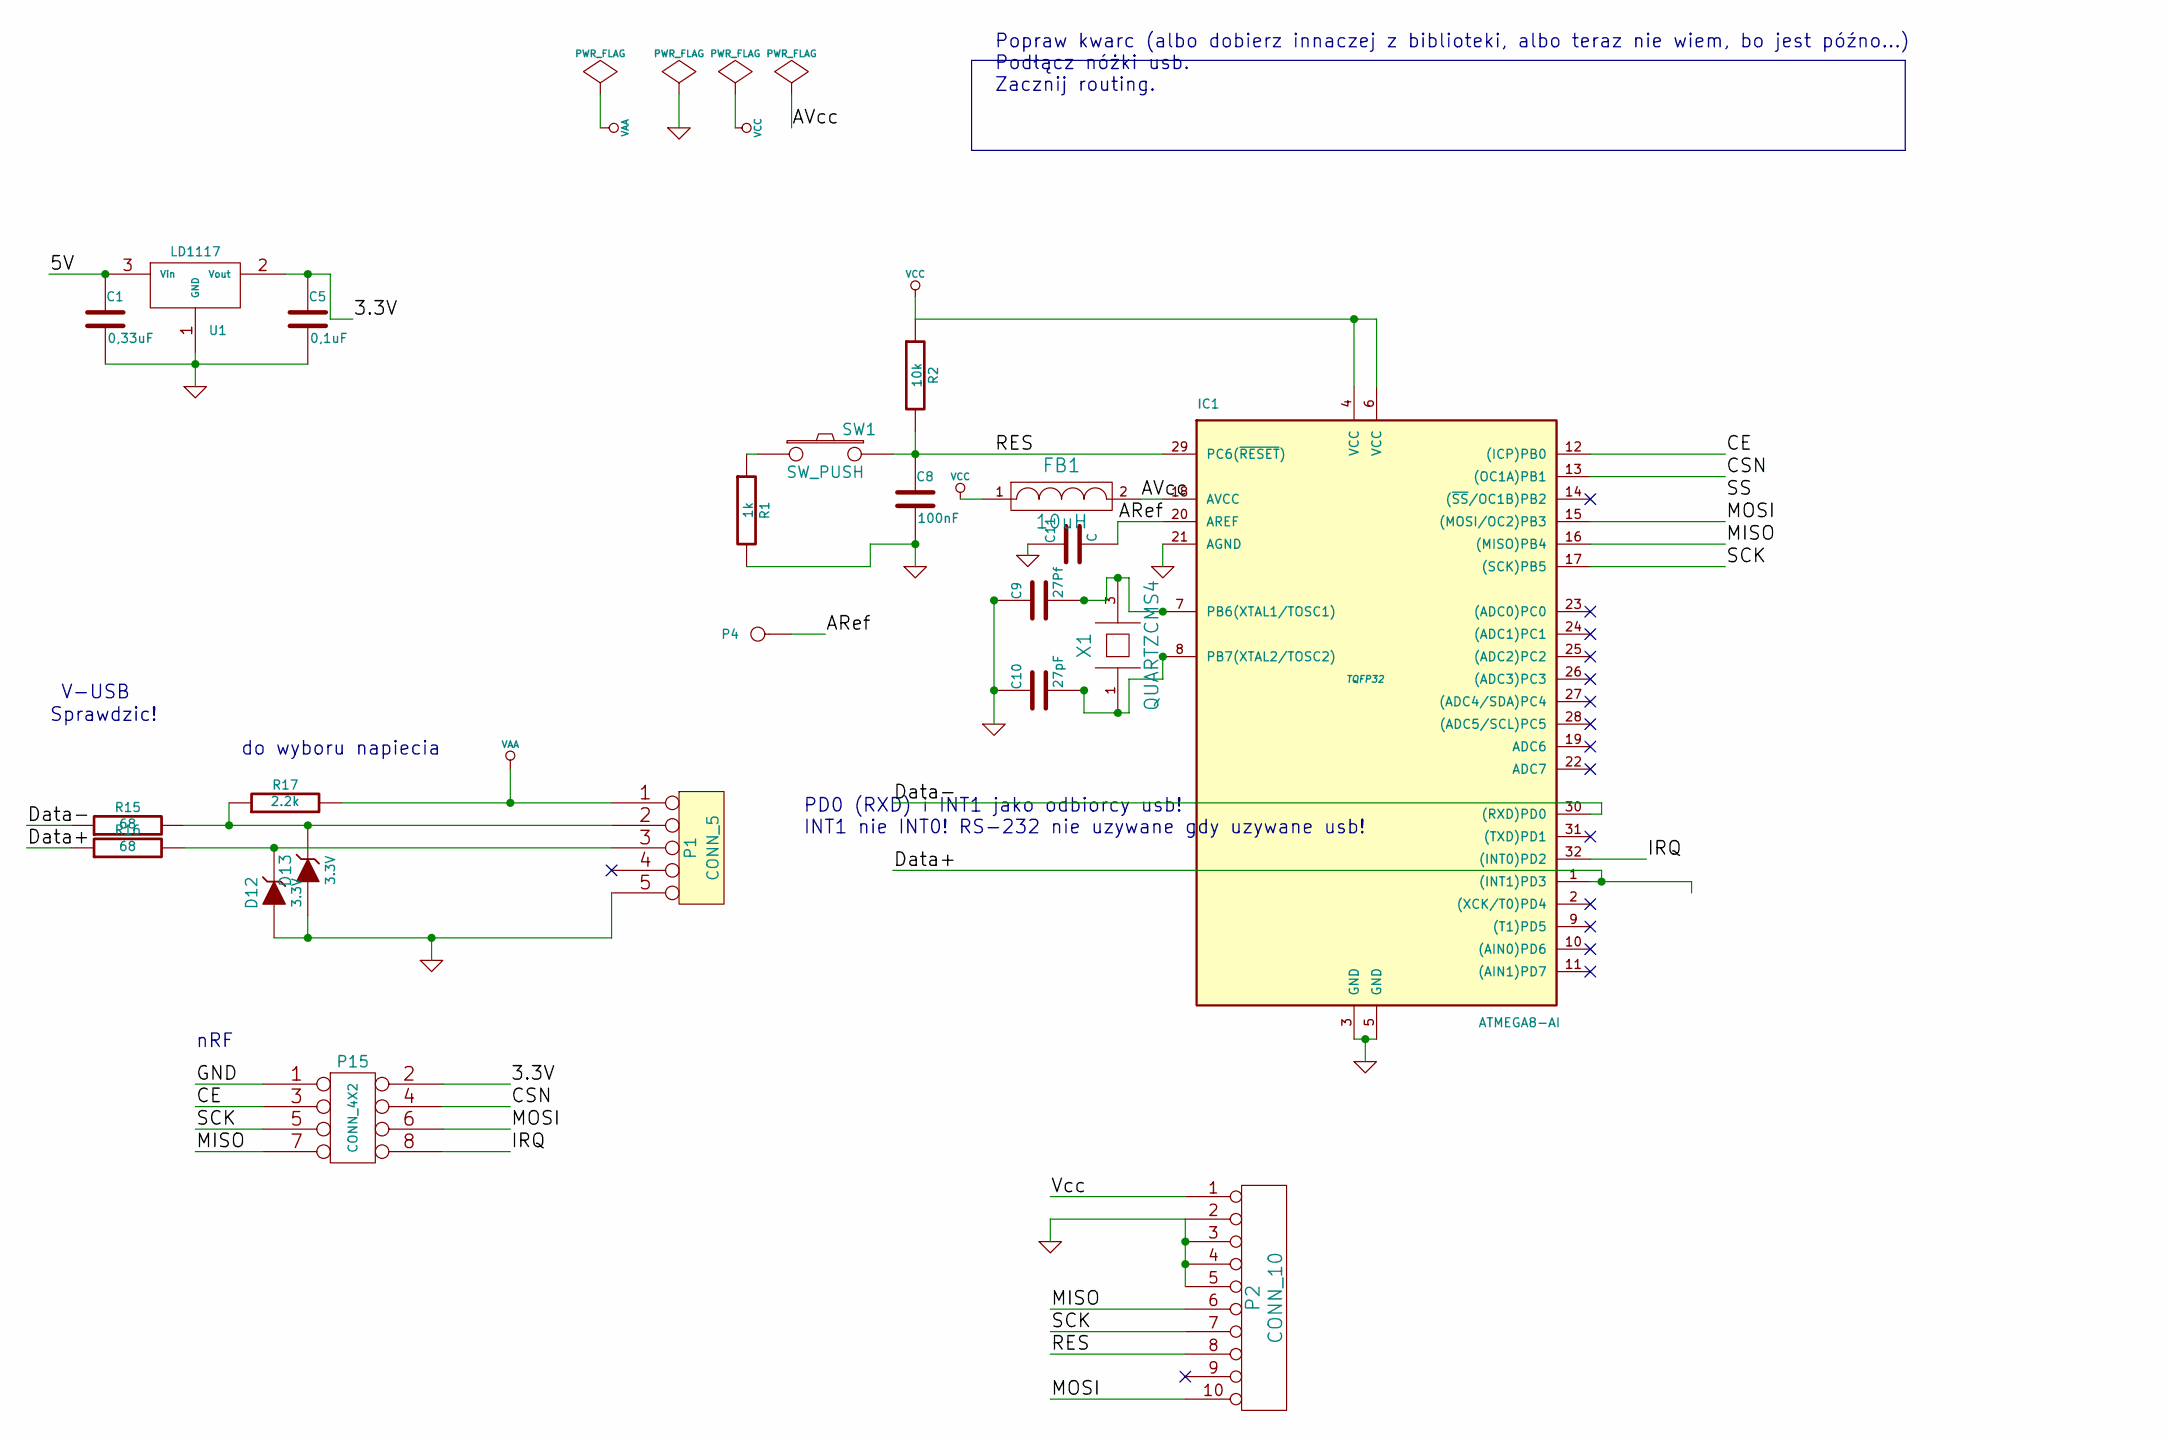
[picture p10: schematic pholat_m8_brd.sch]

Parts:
C1: 0,33uF
C5: 0,1uF
C8: 100nF
C9: 27Pf
C10: 27pF
C11: C
D12, D13: 3.3V
FB1: 10uH
IC1: ATMEGA8-AI; TQFP32
P1: CONN_5
P2: CONN_10
P4: CONN_1
P15: CONN_4X2
R1: 1k
R2: 10k
R15, R16: 68
R17: 2.2k
SW1: SW_PUSH
U1: LD1117
X1: QUARTZCMS4

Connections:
/3.3V: C5.1, P15.2, U1.2 (Vout)
/5V: C1.1, U1.3 (Vin)
/ARef: C11.2, IC1.20 (AREF), P4.1
/AVcc: FB1.2, IC1.18 (AVCC)
/CE: IC1.12 ((ICP)PB0), P15.3
/CSN: IC1.13 ((OC1A)PB1), P15.4
/Data+: IC1.1 ((INT1)PD3), R16.1
/Data-: IC1.30 ((RXD)PD0), R15.1
/IRQ: IC1.32 ((INT0)PD2), P15.8
/MISO: IC1.16 ((MISO)PB4), P2.6, P15.7
/MOSI: IC1.15 ((MOSI/OC2)PB3), P2.10, P15.6
/RES: C8.1, IC1.29 (PC6(~RESET~)), P2.8, R2.2, SW1.2
/SCK: IC1.17 ((SCK)PB5), P2.7, P15.5
GND: C1.2, C5.2, C8.2, C9.1, C10.1, C11.1, D12.1 (A), D13.1 (A), IC1.3 (GND), IC1.5 (GND), IC1.21 (AGND), P1.5, P2.2, P2.3, P2.4, P2.5, P15.1, R1.2, U1.1 (GND)
unnamed: C9.2, IC1.7 (PB6(XTAL1/TOSC1)), X1.3
unnamed: C10.2, IC1.8 (PB7(XTAL2/TOSC2)), X1.1
unnamed: R1.1, SW1.1
unnamed: D12.2 (K), P1.3, R16.2
unnamed: D13.2 (K), P1.2, R15.2, R17.1
VAA: P1.1, R17.2
VCC: FB1.1, IC1.4 (VCC), IC1.6 (VCC), P2.1, R2.1

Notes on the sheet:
nRF
V-USB
Sprawdzic!
PD0 (RXD) i INT1 jako odbiorcy usb! INT1 nie INT0! RS-232 nie uzywane gdy uzywane usb!
Popraw kwarc (albo dobierz innaczej z biblioteki, albo teraz nie wiem, bo jest późno...) Podłącz nóżki usb. Zacznij routing.
do wyboru napiecia

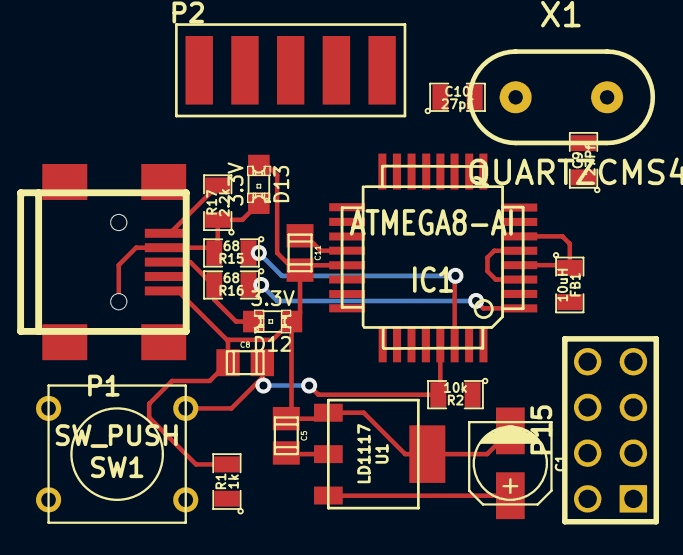
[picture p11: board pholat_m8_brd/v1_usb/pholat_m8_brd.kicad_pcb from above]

Board: 2 copper layers, 21 parts (0 on the bottom side), 21 nets.

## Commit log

2014-01-07 First upload of last version of teensylu-lvlup.
    [Teensylu.kicad_pcb, Teensylu.sch]
2014-01-19 My first git - m8 brd 4 {nRF&USB&5510 screen}
    [.kicad_pcb-B_Cu.gbl, .kicad_pcb-B_Mask.gbs, .kicad_pcb-B_Paste.gbp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]
2014-02-06 KOS-master lil' remake
    [Teensylu.kicad_pcb, Teensylu.sch]
